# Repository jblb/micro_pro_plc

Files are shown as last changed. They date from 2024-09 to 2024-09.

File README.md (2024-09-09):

### A 4 inputs 4 outputs PLC board based on [Arduino micro pro] (or clone) to drive a 4 Way [relay board] and made to run with [open_PLC]

### Status:

work in progress...

__Micro pro PLC__ is a  small _Programable Logic Controlor_ board based on [Arduino micro pro] (ATmega32U4 microcontroler).
It is designed for small systems with 4 digital inputs, 4 digital outputs, 2 analog inputs and a Modbus/RS485 access.
It is designed to fit on easy available 4 way [relay board]

I first designed it for use with [open_PLC] but it can be use with Arduino IDE or any other way you want to devellop the software you put on the controler

### Simulated 3D view

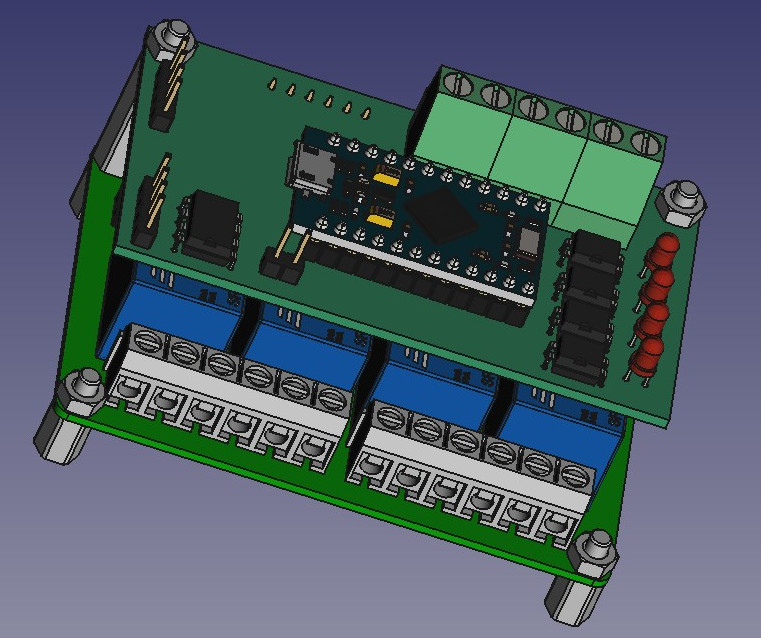
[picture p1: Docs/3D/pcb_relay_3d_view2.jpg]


### Connection diagram

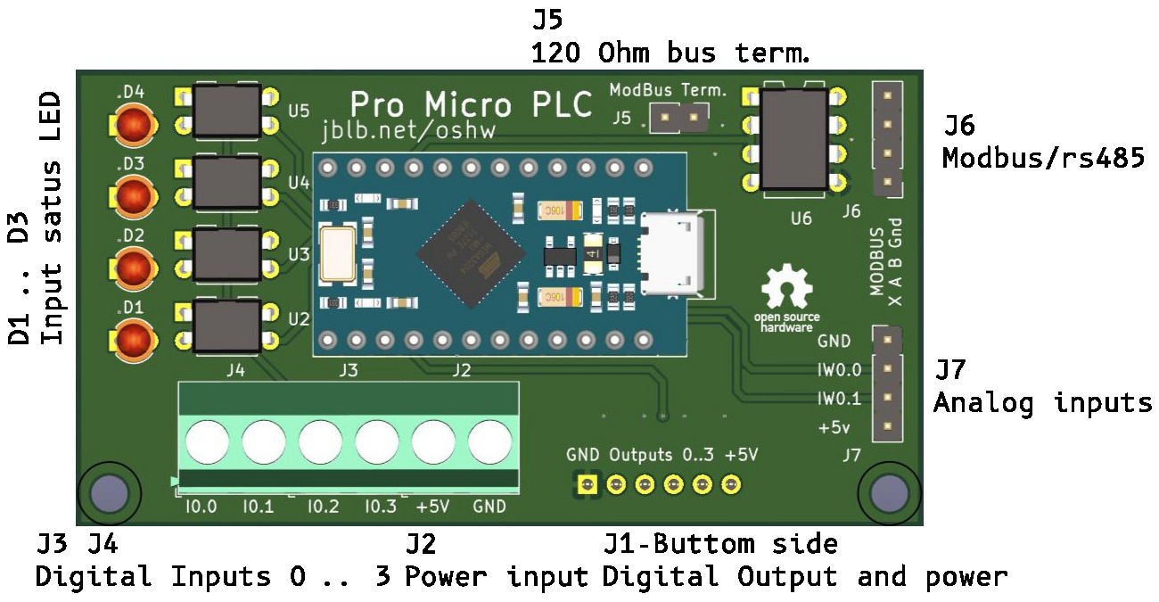
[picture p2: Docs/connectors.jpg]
Connection diagram


### Arduino pins used

| Board pin | Arduino pin |
| :--- | :---|
| I0.0 | D2 |
| I0.1 | D3 |
| I0.2 | D4 |
| I0.3 | D5 |
| Output0 | D7 |
| Output1 | D8 |
| Output2 | D14 |
| Output3 | D15 |
| IW0.0 | A0 |
| IW0.1 | A1 |

- Modbus/RS485 drived by D1 for Tx and D0 for RX (Serial1)
- RS485 is enabled by D6
- Outputs open drain - 200mA drain output
- Input actived by pooling to GND (need to drain ~20mA)

### Schematic

Schematic

PDF version available [here](./Docs/pro_micro_plc_sch.pdf)

### BOM
|Reference |Value |Footprint|
|:---|:-----|:---|
|C1,C2,C3  |100nF |SMD 0805 |
|D1,D2,D3,D4 |LED_3mm ||
|J1 |01x06_Pin |PinSocket_2.54mm |
|J2,J3,J4 ||TerminalBlock_Phoenix_MKDS 5.00mm |
|J5 |01x02_Pin |PinHeader_2.54mm |
|J6,J7 |01x04_Pin |PinHeader_2.54mm or JST HX|
|Q1,Q2,Q3,Q4 |2N7002K |SOT-23 |
|R1,R2,R3,R4 |10k |SMD 0805 |
|R5,R6,R7,R8 |4k7 |SMD 0805 |
|R9 |120 |SMD 0805 |
|R10,R11,R12,R13 |100 |SMD 0805 |
|R14,R15 |20k |SMD 0805 |
|U1 |Sparkfun_Pro_Micro or Clone|
|U2,U3,U4,U5 |PC817 |DIP4 |
|U6 |MAX485E |DIP8 |

also available [here](./Docs/pro_micro_plc_BOM.md)

[open_PLC]: https://autonomylogic.com/
[Arduino micro pro]: https://www.sparkfun.com/products/12640
[relay board]: https://fr.aliexpress.com/item/1005002867727977.html

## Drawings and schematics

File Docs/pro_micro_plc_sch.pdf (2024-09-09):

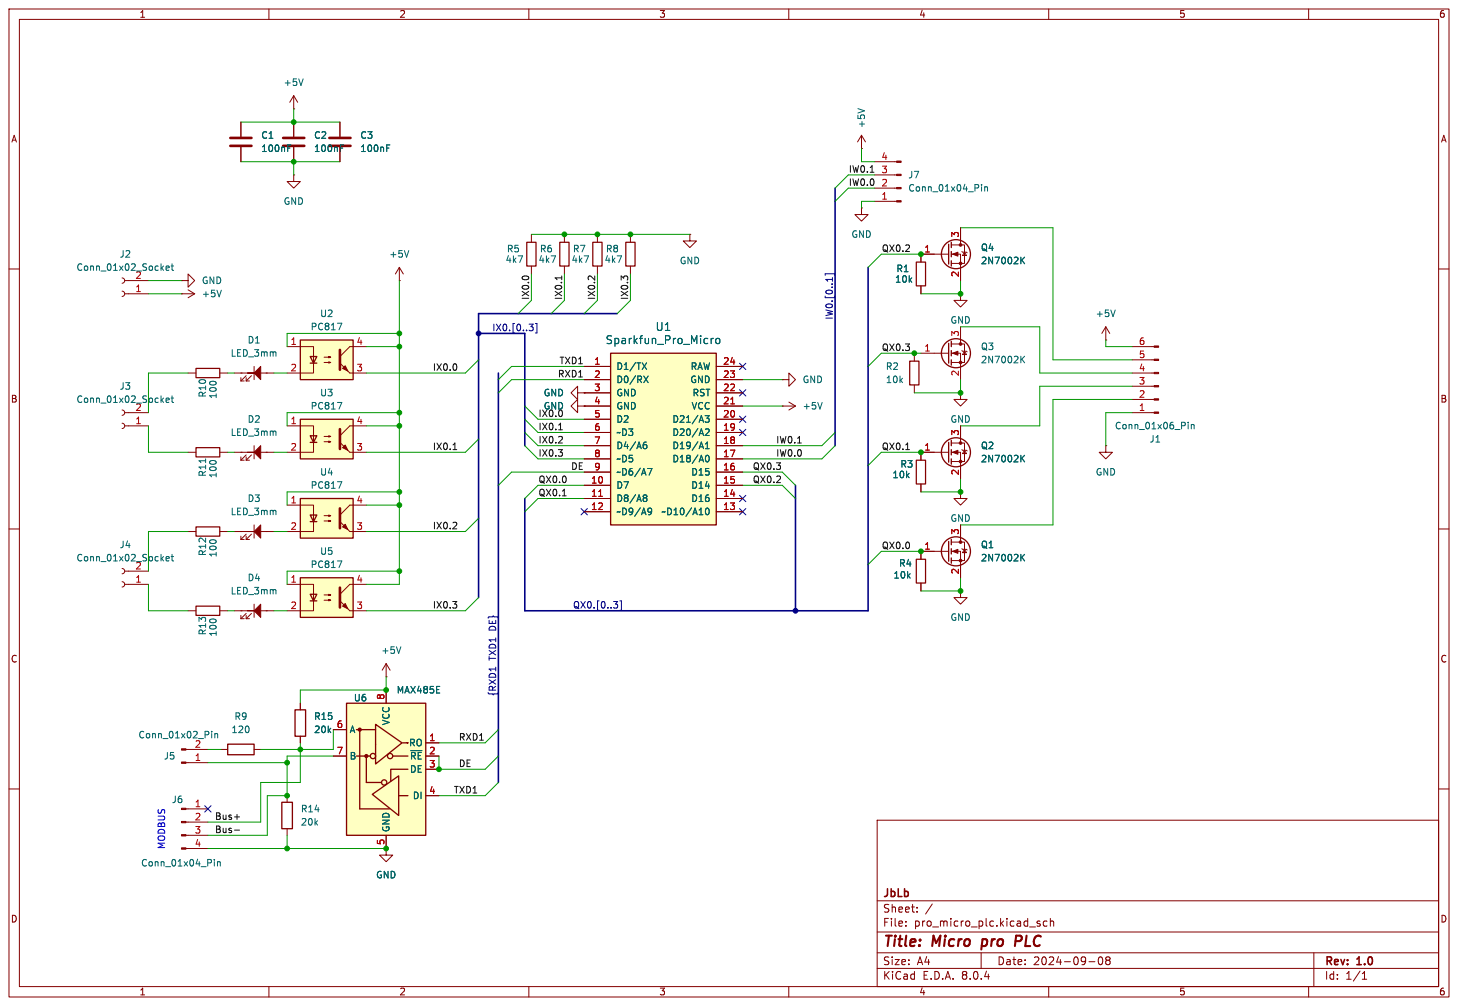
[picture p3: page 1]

2 3 U1 Sparkfun_Pro_Micro D1/TX 1 D7 10 D8/A8 11 ~D9/A9 12 ~D10/A10 13 D16 14 D14 15 D15 16 D18/A0 17 D19/A1 18 D20/A2 19 D0/RX 2 D21/A3 20 VCC 21 RST 22 GND 23 RAW 24 GND 3 GND 4 D2 5 ~D3 6 D4/A6 7 ~D5 8 ~D6/A7 9 GND GND GND

Id: 1/1 Title: Micro pro PLC

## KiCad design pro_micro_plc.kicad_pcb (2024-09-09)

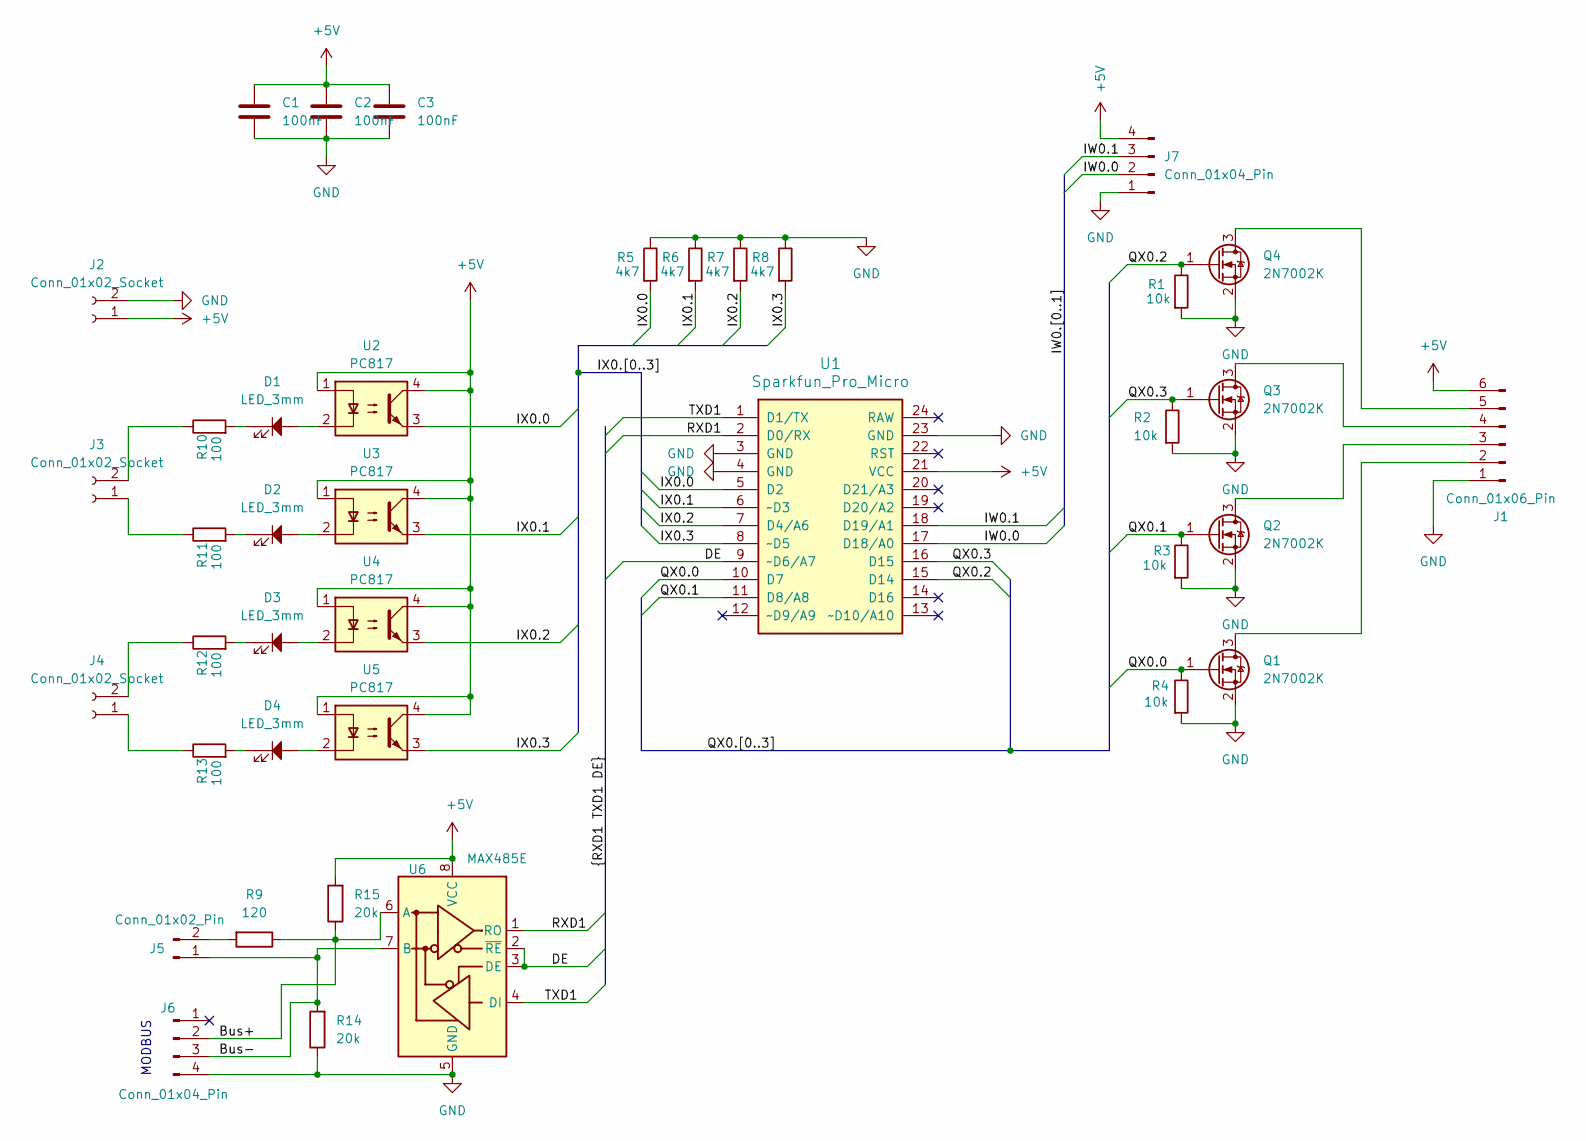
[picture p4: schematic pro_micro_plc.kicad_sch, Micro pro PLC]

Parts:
C1, C2, C3: 100nF; C_0805_2012Metric_Pad1.18x1.45mm_HandSolder
D1, D2, D3, D4: LED_3mm; LED_D3.0mm
J1: Conn_01x06_Pin; PinSocket_1x06_P2.54mm_Vertical
J2, J3, J4: Conn_01x02_Socket; TerminalBlock_Phoenix_MKDS-1,5-2_1x02_P5.00mm_Horizontal
J5: Conn_01x02_Pin; PinHeader_1x02_P2.54mm_Vertical
J6, J7: Conn_01x04_Pin; PinHeader_1x04_P2.54mm_Vertical
Q1, Q2, Q3, Q4: 2N7002K; SOT-23_Handsoldering
R1, R2, R3, R4: 10k; R_0805_2012Metric_Pad1.20x1.40mm_HandSolder
R5, R6, R7, R8: 4k7; R_0805_2012Metric_Pad1.20x1.40mm_HandSolder
R9: 120; R_0805_2012Metric_Pad1.20x1.40mm_HandSolder
R10, R11, R12, R13: 100; R_0805_2012Metric_Pad1.20x1.40mm_HandSolder
R14, R15: 20k; R_0805_2012Metric_Pad1.20x1.40mm_HandSolder
U1: Sparkfun_Pro_Micro
U2, U3, U4, U5: PC817; DIP-4_W7.62mm
U6: MAX485E; DIP-8_W7.62mm

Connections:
+5V: C1.1, C2.1, C3.1, J1.6, J2.1, J7.4, R15.2, U1.21 (VCC), U2.1, U2.4, U3.1, U3.4, U4.1, U4.4, U5.1, U5.4, U6.8 (VCC)
/Bus+: J6.2, R9.1, R15.1, U6.6 (A)
/Bus-: J5.1, J6.3, R14.2, U6.7 (B)
/DE: U1.9 (~D6/A7), U6.2 (~RE), U6.3 (DE)
/IW0.0: J7.2, U1.17 (D18/A0)
/IW0.1: J7.3, U1.18 (D19/A1)
/IX0.0: R5.1, U1.5 (D2), U2.3
/IX0.1: R6.1, U1.6 (~D3), U3.3
/IX0.2: R7.1, U1.7 (D4/A6), U4.3
/IX0.3: R8.1, U1.8 (~D5), U5.3
/QX0.0: Q1.1 (G), R4.2, U1.10 (D7)
/QX0.1: Q2.1 (G), R3.2, U1.11 (D8/A8)
/QX0.2: Q4.1 (G), R1.2, U1.15 (D14)
/QX0.3: Q3.1 (G), R2.2, U1.16 (D15)
/RXD1: U1.2 (D0/RX), U6.1 (RO)
/TXD1: U1.1 (D1/TX), U6.4 (DI)
GND: C1.2, C2.2, C3.2, J1.1, J2.2, J6.4, J7.1, Q1.2 (S), Q2.2 (S), Q3.2 (S), Q4.2 (S), R1.1, R2.1, R3.1, R4.1, R5.2, R6.2, R7.2, R8.2, R14.1, U1.3 (GND), U1.4 (GND), U1.23 (GND), U6.5 (GND)
unnamed: D1.1, R10.1
unnamed: D1.2, U2.2
unnamed: D2.1, R11.1
unnamed: D2.2, U3.2
unnamed: D3.1, R12.1
unnamed: D3.2, U4.2
unnamed: D4.1, R13.1
unnamed: D4.2, U5.2
unnamed: J1.2, Q1.3 (D)
unnamed: J1.3, Q2.3 (D)
unnamed: J1.4, Q3.3 (D)
unnamed: J1.5, Q4.3 (D)
unnamed: J3.1, R11.2
unnamed: J3.2, R10.2
unnamed: J4.1, R13.2
unnamed: J4.2, R12.2
unnamed: J5.2, R9.2

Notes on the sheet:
MODBUS

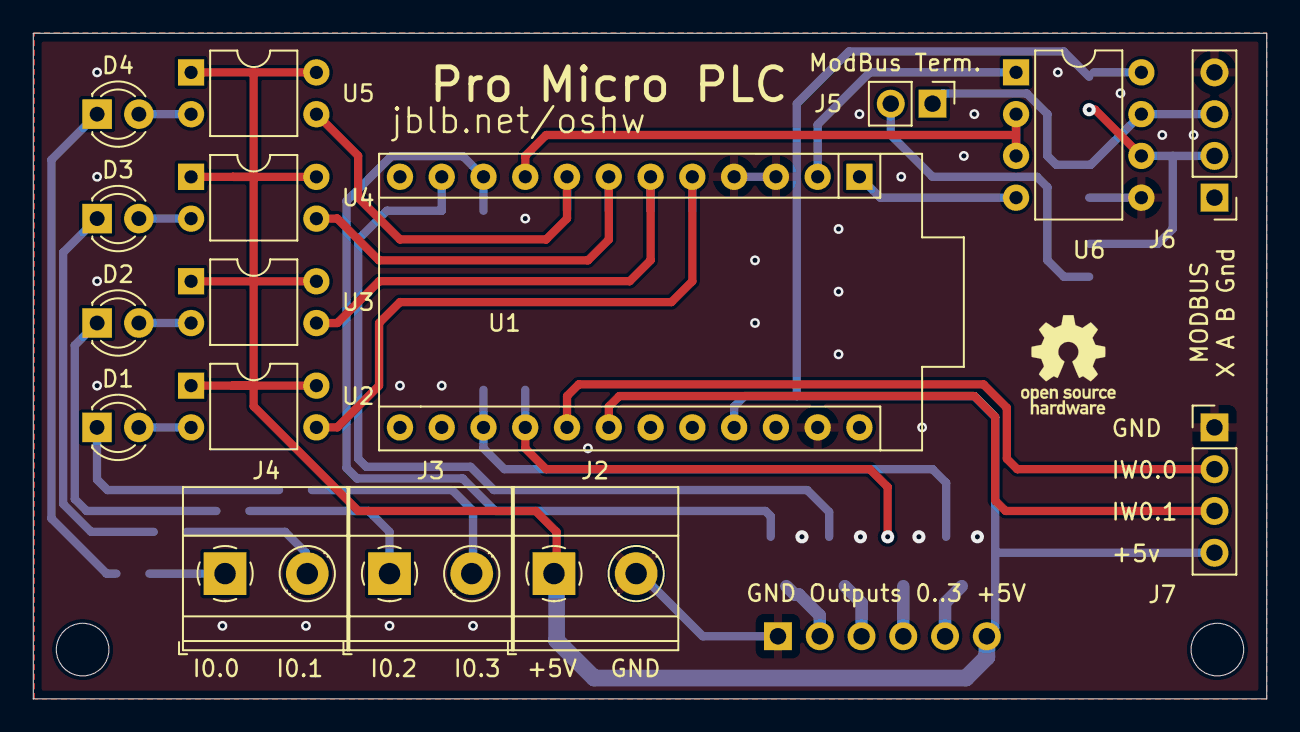
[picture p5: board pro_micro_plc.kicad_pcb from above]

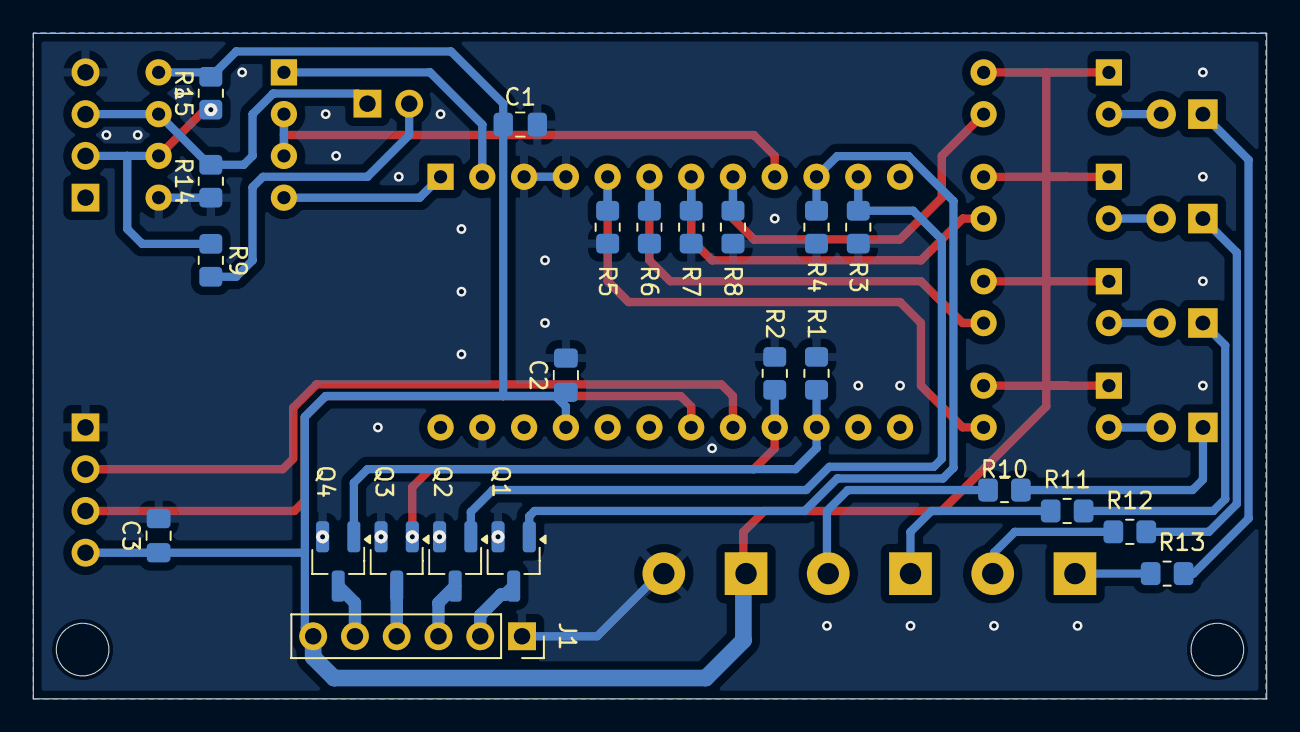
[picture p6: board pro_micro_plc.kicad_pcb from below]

Board: 2 copper layers, 75.0 x 40.5 mm, 39 parts (23 on the bottom side), 34 nets.

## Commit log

2024-08-25 initial board stuff
    [pro_micro_plc.kicad_pcb, pro_micro_plc.kicad_sch]
2024-08-25 rename reps
    [pro_micro_plc.kicad_pcb, pro_micro_plc.kicad_sch]
2024-08-25 add analog input
    [pro_micro_plc.kicad_pcb, pro_micro_plc.kicad_sch]
2024-08-26 smallest PCB
    [pro_micro_plc.kicad_pcb]
2024-08-28 more space for max485 and vias on ground
    [pro_micro_plc.kicad_pcb, pro_micro_plc.kicad_sch]
2024-09-06 update terminal blocks
    [pro_micro_plc.kicad_pcb, pro_micro_plc.kicad_sch]
